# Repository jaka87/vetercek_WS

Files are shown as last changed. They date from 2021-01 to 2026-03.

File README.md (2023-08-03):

# Vetercek.com weather station
This project was created in order to provide cheap alternative to expensive autonomous weather stations. The goal is to create robust weather station that would require (almost) no maintenance. As mentioned in the title the data would be send to **vetercek.com** but with some modification other services could be included. Keep in mind that most attention is dedicated to measure wind since is used mostly by windsurfers, kiters and other wind enthusiast. In general we tried to keep the cost as low as possible on the other hand in some areas like for example anemometer we went with durable and well calibrated instead of cheap.

## Connecting options
+ [latest version with 7070 chip](vetercek_SIM7070) 
+ [old 7000 chip](vetercek_nb-iot-HW) 

## License
This project is released under
The GNU Lesser General Public License (LGPL-3.0)

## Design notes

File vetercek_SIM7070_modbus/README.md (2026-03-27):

# Vetercek.com weather station nb-iot
New PCB  
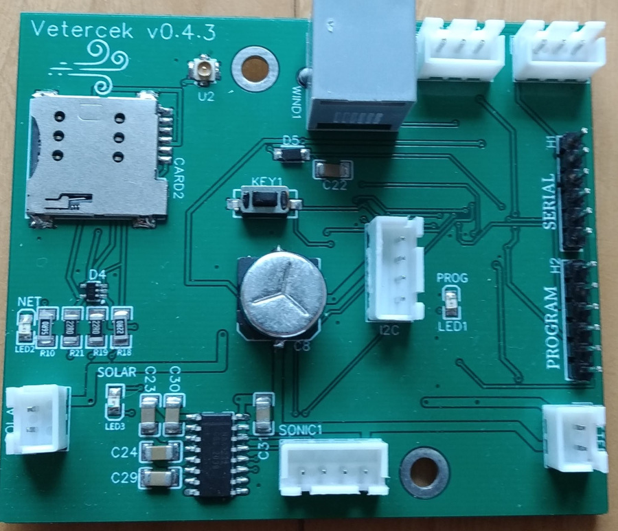
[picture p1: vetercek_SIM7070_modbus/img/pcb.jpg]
PCB
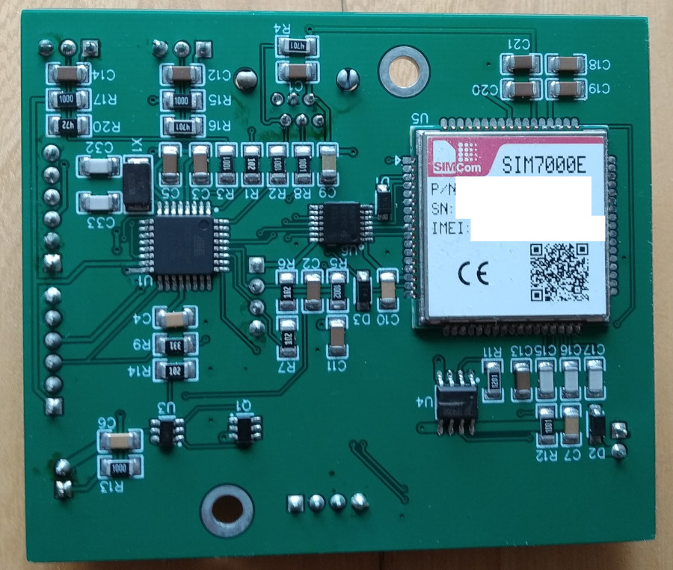
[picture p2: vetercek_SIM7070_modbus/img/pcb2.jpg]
PCB back
    

## Features of the WS
+ Send wind speed and gusts to the server
+ Send water and air temperature to the server
+ Send WS battery state to the server
+ Remote adjustment of the time between updates (depending on sever response)
+ Remote adjustment of wind wane offset (depending on sever response)
+ Wind speed and direction are measured for 2 second every 10 seconds (adjustable). It is a good compromise for accurate measurements and long battery life.
+ **New** switched from HTTP and MQTT to custom UDP protocol - for speed, reliability and better battery consumption 
+ **New** new GPRS modul that supports both nb-iot and also 2G (Thanks to [A1](https://www.a1.si/) and [Telekom Slovenije](https://www.telekom.si/) for providing me with nb-iot sim cards). With new module there is much faster data upload and lower battery consumption. Therefore I also enabled fast data upload that can be enabled when you need data upload every few secconds as opposed to few minutes.

## Required parts
+ ultrasonic anemometer RS232 
+ PCB with SIM7000E module 
+ SIM card 
+ 5 or 6V Solar Power Panel 
+ 3.6V li-ion batteries
+ Waterproof housing
+ GSM antena
+ DS18B20 temperature sensor
+ Cable gland for anemometer cable, solar and temperature sensor

## Optional parts
+ Rain gauge (whichever uses reed switch in tipping bucket)
+ BMP280 pressure sensor

## Payload
UDP payload using this station is 24 byte for upload and 9 bytes for server response  
**sample upload:**  
list=[11,11,11,11,11,11,11,1,   1,77, 12,2, 14,5, 1,20,3, 0,1,0, 77,18,40,0.88,12,34]  
+ first 8 bytes are id of the station
+ byte 9 and 10 are for wind wane -  (sample 177)
+ byte 11 and 12 are wind speed (sample 12.2 KT)
+ byte 13 and 14 are for gusts (sample 14.5 KT)
+ byte 15-17 are for air temperature (sample +20.3 C)
+ byte 18-20 are the same as above exept for water temperature (sample -1.0 C) or rain data
+ byte 21 is battery percentage (sample 77%)
+ byte 22 is signal 
+ byte 23 is count of measurements
+ byte 24 is reset reason  
+ byte 25 is solar current  
+ byte 26,27 is pressure measurement  

list=[40, 1,2,30, 23, 1, 5, 1, 0]  
**sample response:**
+ byte 1 is measure count - after how many measurements do the next data upload (sample 40)
+ byte 2-4 is for wind wane offset - (sample 230)
+ byte 5 is wind measurement timer (on client side this number is muultiplied by 10) - (sample 2300)
+ byte 6 controls tmp sensor - 0 off; 1 only air, 2 only watter; 3 both
+ byte 7 controsl cuttof wind  - when avg wind is under that value data is send 2x of setted interval
+ byte 8 - 0 no sleep between wind measurements, 1 - 8s delay
+ byte 9 - 1 resets the station, other numbers change settings of rain/water sensor, solar measurement, pressure measurement...

## Arduino pro mini
Arduino pro mini has different bootloader than Uno (older) that has watchdog bug that puts your arduino in endless loop. I solved this with uploading with programmer (skipping bootloader). If you wish to use bootloader I suggest Minicore. 

## Scheme
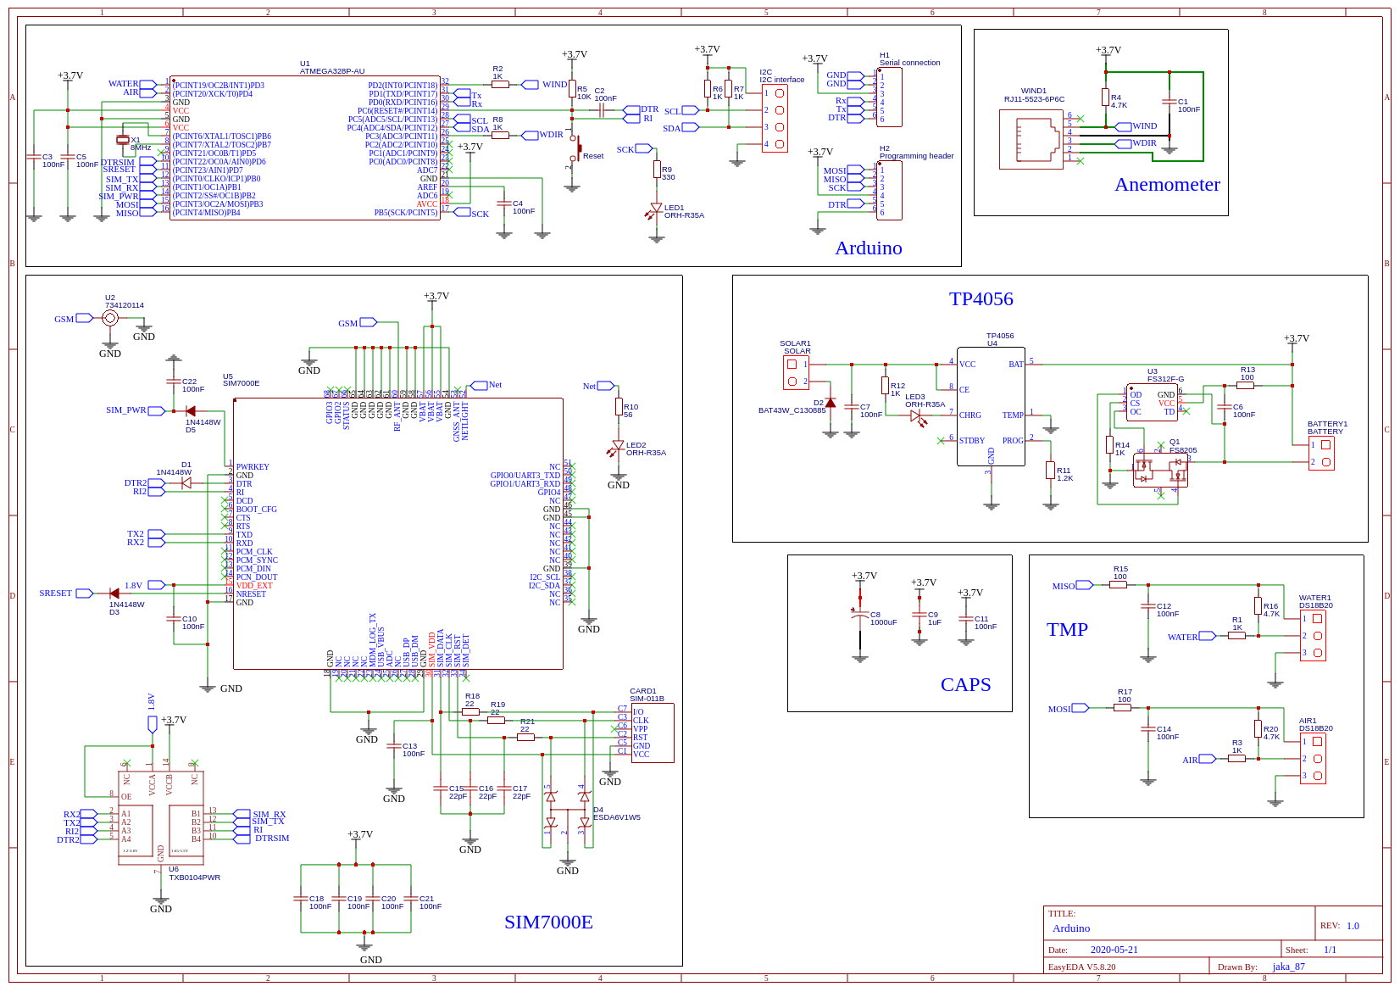
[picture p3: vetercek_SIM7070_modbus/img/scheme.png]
Scheme
  
Here is the [link](https://easyeda.com/jaka87/new-vetercek) to PCB design.  

## TO-DO
+ Currently there are no planned updates. WS seems stable and (almost) ready for production

## Libraries used in this project
All the libraries are uploaded in src folder. Most of them are stock libraries but i did quite some modification os SIM7000 library 

## Power consumption
In sleep 1-1.5mA  
Idle 4-5 mA (Davis anemometer) and 20-25mA (ultrasonic anemometer)   
Sending data 100-200mA  

## Thanks!
Thanks to all of you contributing to make this happen. Especially thanks to Tadej Tašner for drawing PCB and his advices regarding the hardware components. Also thanks to those people that took time and wrote libraries used in this project and therefore make the project easier to compile.

Contributing to this software is warmly welcomed. You can use it, change it, do what ever you want with it.

## License
This project is released under
The GNU Lesser General Public License (LGPL-3.0)

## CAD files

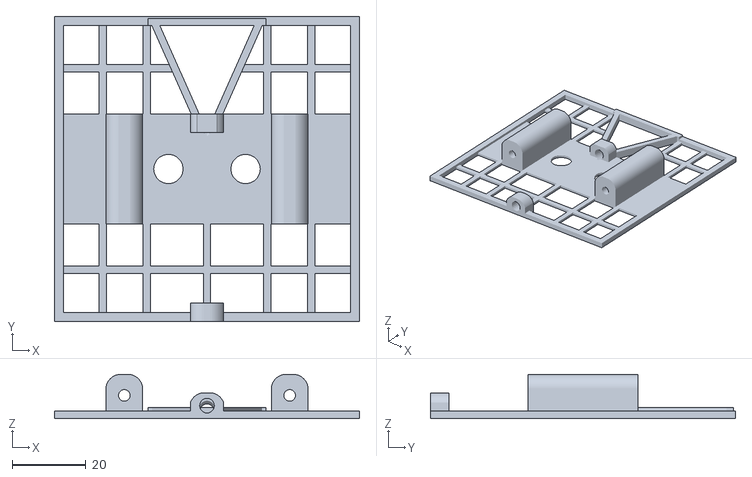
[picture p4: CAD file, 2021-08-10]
3D prints/solar/solar glued v2.stl
83.0 x 83.0 x 12.0

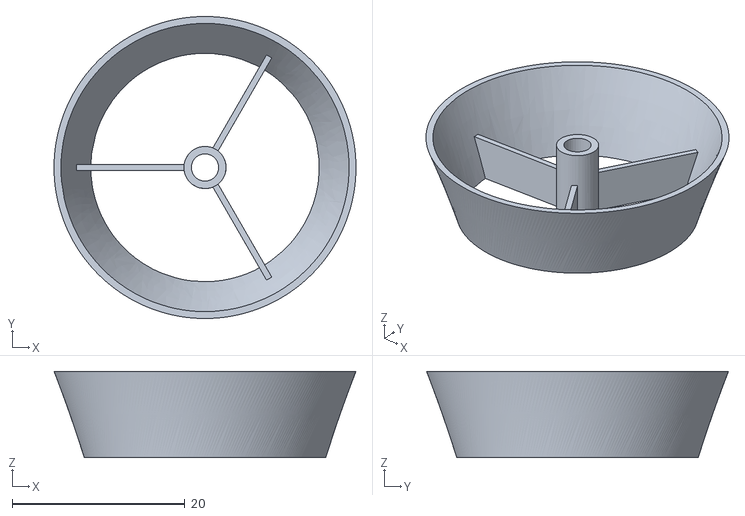
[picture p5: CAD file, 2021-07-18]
3D prints/tmp/35mm/tmp.stl
35.0 x 35.0 x 10.0

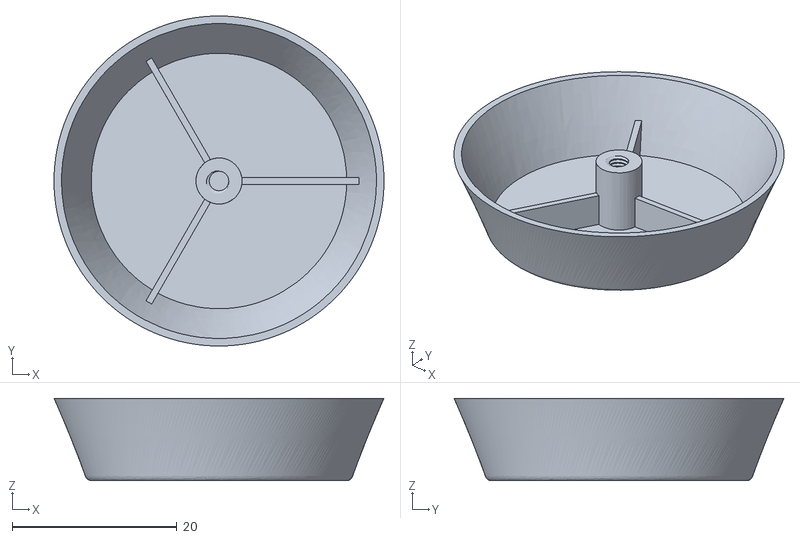
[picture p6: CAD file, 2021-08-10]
3D prints/tmp/40mm/tmp - top.stl
40.0 x 40.0 x 10.00

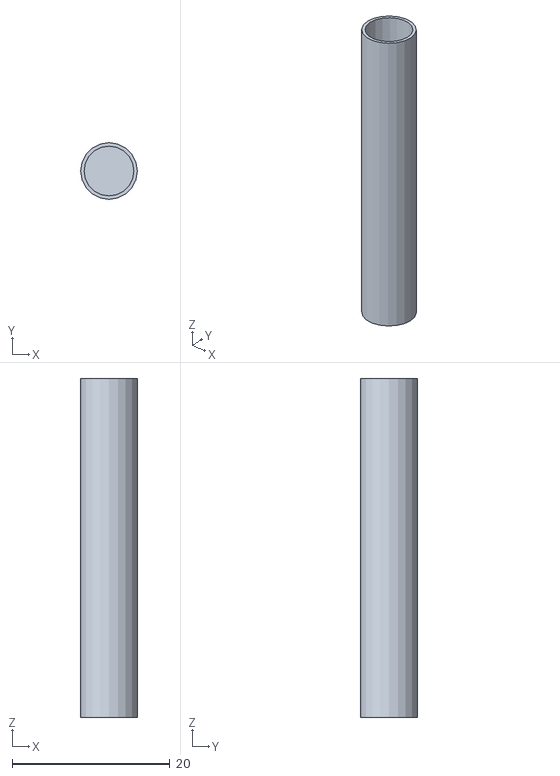
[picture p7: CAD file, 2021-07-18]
3D prints/tmp/tmp pipe.stl
7.20 x 7.20 x 43.0

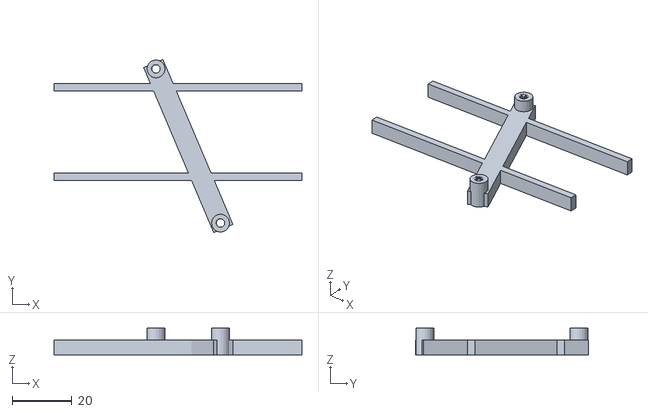
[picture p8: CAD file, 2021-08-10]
3D prints/WS box/PCB holder UZ.stl
83.0 x 58.0 x 9.00

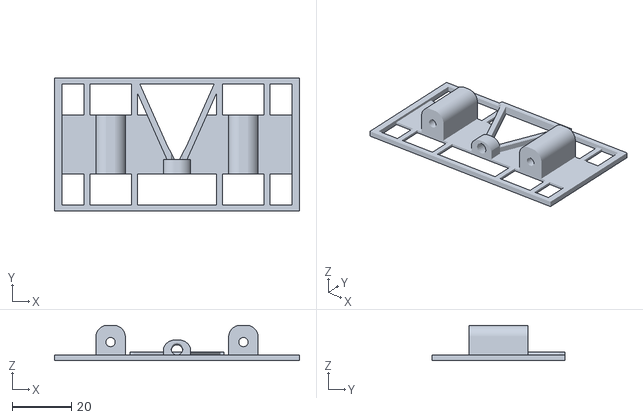
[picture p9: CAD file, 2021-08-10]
3D prints/solar/solar glued v2 small.stl
83.0 x 45.0 x 12.0

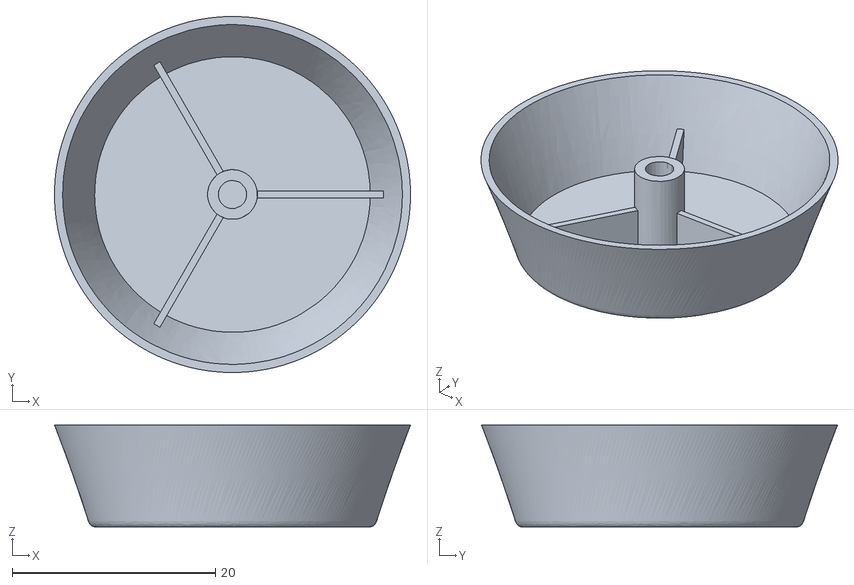
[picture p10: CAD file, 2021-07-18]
3D prints/tmp/35mm/tmp cover.stl
35.0 x 35.0 x 10.0

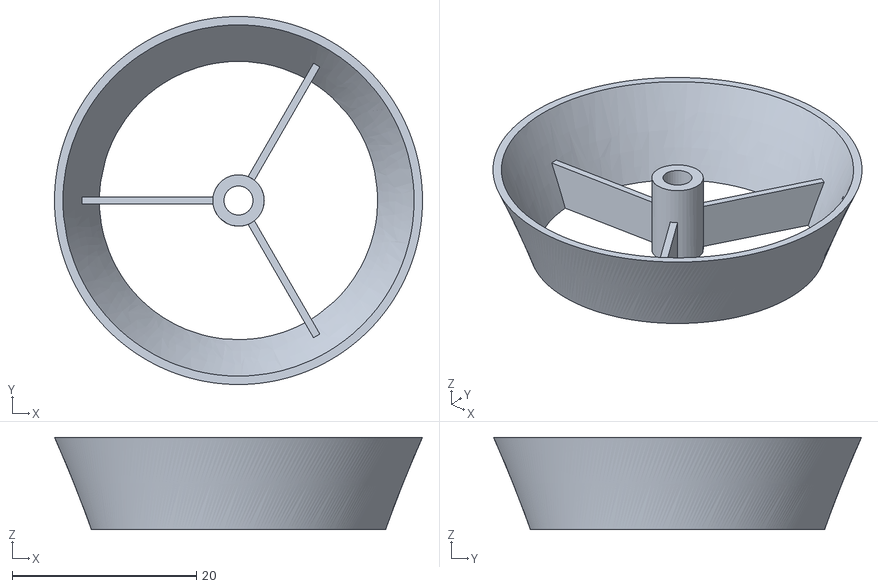
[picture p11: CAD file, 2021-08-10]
3D prints/tmp/40mm/tmp - midle.stl
40.0 x 40.0 x 10.0

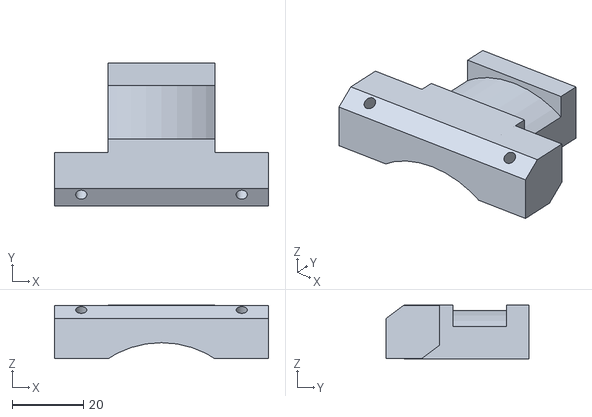
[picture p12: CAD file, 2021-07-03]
3D prints/solar/pole mount solar.stl
60.0 x 40.0 x 15.0

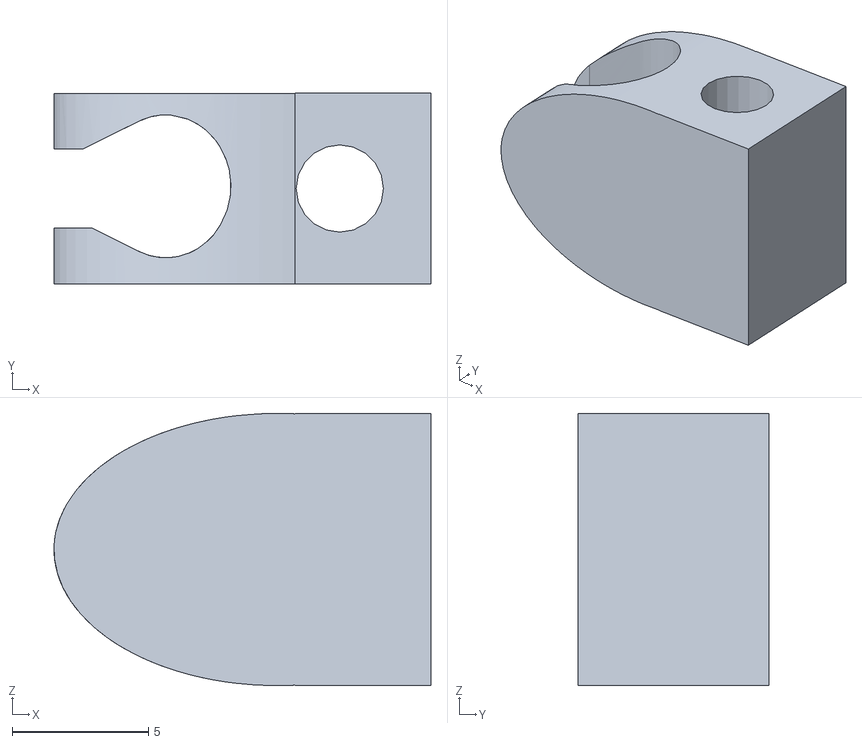
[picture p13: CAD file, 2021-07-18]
3D prints/tmp/35mm/cable clip2.stl
13.8 x 7.00 x 10.0

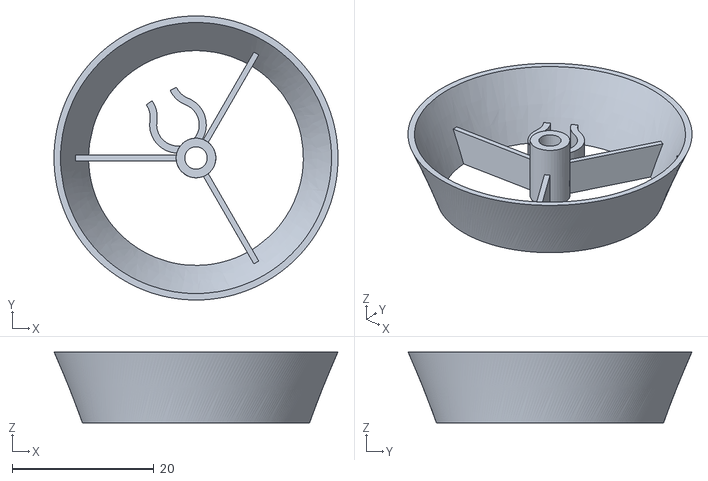
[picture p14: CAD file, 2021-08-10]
3D prints/tmp/40mm/tmp - bottom.stl
40.0 x 40.0 x 10.0

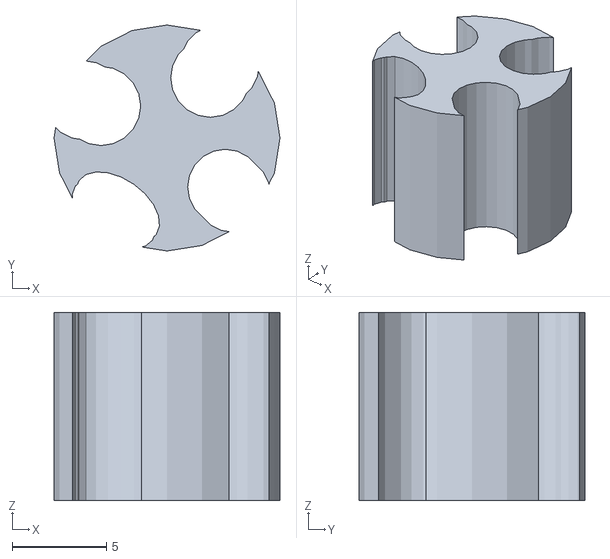
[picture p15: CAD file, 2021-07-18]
3D prints/WS box/PG gland insert 4.stl
12.0 x 12.0 x 10.0

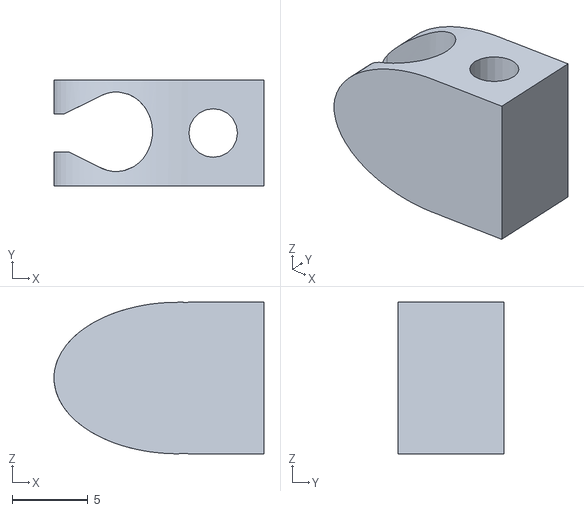
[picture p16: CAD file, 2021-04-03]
3D prints/tmp/35mm/cable clip.stl
13.9 x 7.00 x 10.0

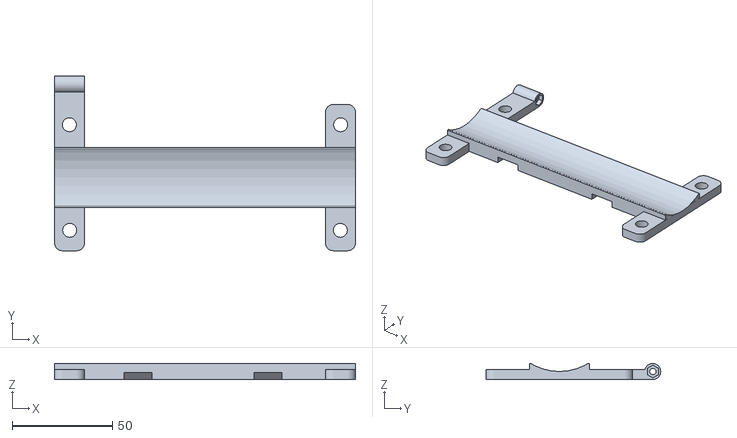
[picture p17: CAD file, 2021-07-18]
3D prints/WS box/box holder.stl
150.1 x 87.0 x 8.00

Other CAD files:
3D prints/WS box/PCB holder Davis.stl
3D prints/WS box/PG gland insert 3.stl
3D prints/solar/solar glued.stl

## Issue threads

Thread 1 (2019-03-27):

Doube data send in matter of few seconds

jaka87, 2019-03-27:
Once or twice a day data is send twice in matter of 30-60 seconds of one another, while second upload contains only one measurement. Im not sure exactly where the problem occurs or if its a problem with my code or SIM800 library.

The second upload contains only one measurement so wind speed and gust are identical. This should not have happen. I tried to add locking mechanism in loop function but that didn't solve the problem. Now I added second if condition in senddata() hoping it will solve it...

It could be caused by random arduino board reset. Im looking into it. Opinions welcomed.

jaka87, 2019-03-27:
It might very well be that arduino reset itself because of problem with serial print buffer. Some changes have been made to enable/disable debug mode. Few days of testing will show if error is fixed...

jaka87, 2019-04-01:
I tested with turned off serial print and increased posting frequency (to increased chances of error if issue still persist) and it appears the issue is still there

jaka87, 2019-04-02:
Some debugging has showed that error is caused by arduino board reset. Now the question is, if reset is because hardware malfunction or memory error. I will make an update in the evening with the function to display available memory on every post to see which one is it.

jaka87, 2019-04-03:
Latest commit seems to fix the issue. The problem was that somewhere down the line i removed the water sensor initial command by mistake. I also split water and temperature sensor reading to two different functions. Now battery is much more stable, error haven't shown up until now. Hope this is finally fixed.

jaka87, 2019-04-08:
After minor software update and checking the pins the error didn't appear in few days. Mark as solved. Fingers crossed.

Closed 2019-04-08.

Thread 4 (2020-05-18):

ultrasonic anemometer

jaka87, 2020-05-18:
The plan is to create cheap ultrasonic anemometer with good stability in all weather conditions and reasonable accuracy around 1 m/s or less.

Unfortunately my knowledge in this area is lacking but Im slowly learning and i hope that one day we will have working product. The principle is quite simple. Transmitter sends ultrasonic signal to receiver which measure time it took for this process. I first tried to use HC-SRO4 ultrasonic arduino module which is cheap an aveliable. I did some measurements and got accuracy of 1%. I thought this will be enough until i did some calculations. As it turns out i would need repeatability of less than  1 us but in reality my results were +- 5 us. Then I came up with neet idea to make 100 measurements, order it by time and use only 40-50 on that list to calculate average. That did improve results but not near enough for needed accuracy.

I found out that HC-SRO4 transmitter uses 40KHz and has amplitude of 25us and that this is just not enough to accurately measure time of flight - "tof". I search online and find couple of similar projects. I read them many times since its difficult topic for me. My knowledge did improve but im still not certain that i understand it well enough. The most important part of the design is analog component that amplifys signal  detect envelope and phase changes. Counting phase changes should give much more repeatable results.

Antiath, 2020-05-18:
I sure didn't expect to be notified out of nowhere about this subject.
So...about my part.
First of all, my version of this project is, as of today, still unfinished. I got together a prototype on perfboard that was kind of working. A lot of work and multiple revisions  had already been done. I decided to tanslate this prototype on a proper pcb but  those pcb didn't work and destroyed a bunch of pricey components. I got extremely frustrated and stopped working on it. I do plan on getting back to it (the device is actually just beside me right now) when motivation and time are available.

Now for what I can contribute on this, here are a few things I can mention:

1) My design is heavily inspired by Lukas's and carl's versions. It's a mix of both with my own tweaks.  But as the pcb files are clearly no good, there is no point in sharing my schematics. Sorry.

2) This is a crucial point : I use sully enclosed waterproof transceivers similar to these ( in shape only, not necessarly in performance):
https://im01.itaiwantrade.com/b6707fc1-c8f0-43e2-8f2c-90ac3ec62dbf/sensor_40CA-18S-2_thumb_630_447-480x480.jpg
I think this is important  because those things will go outside and they have to survive even in nasty conditions ( like heavy wind and heavy rain).
This way, I get signals that are way way lower in amplitude compared to the kind of open transceivers used HC-SRO4. It is still manageable but this means I need to crank up as much as possible the amplitude the signal I send . And also I need to put extra care on the amplifier on the receiving end.  Fortunatly for us, we deal with onely one frequency (40khz) so it is not impossible to extract from a noisy signal.

3) You are right, I did decide to use a Teensy 3.6 in the end. It can be programmed using the arduino environment (altough it needs special C code for the square signal generation, the kind of thing you won't find in arduino libraries or on the arduino forums) and it is blasing fast for a microcontroller ( and now the teensy 4 is even faster). That or Lukas's pic32 give plenty of margin to be able to do some math without slowing the whole system down. And, most importantly, they can actually output 40khz square signals without issues. The arduino can barely do it on it's own it just can't sample the received signals fast enough with its slow adc.

4) The phase detection part is hard. Very hard. For a lot of tricky reasons. The working prototype I have( the one on perf board) is using Lukas' method of detection. I fiirst detect the actual packet with the treshold method. Then I detect the zero crossings of each 40 khz oscillations and I use those to trigger the adc to do a sample of the received ( amplified) signal on the maximums and minimums of the packet ( so at least one sample at every 40 khz oscillation, on the high and low peaks). This gives me a very rough measure of the shape of the packet.  To mesure the phase, you have two options:

-you try and find the maximum  of the whole packet,  wich may not be the highest peak, it is probably somewhere in between two oscillations. So anywhere in a 25 µs span... Not very good... the peaks of those oscillation almost form a parabola so you can try to calculate the position of the maximum of this parabola with a bit of math ( method described in chapter 2.1 of this article: https://www.imeko.org/publications/wc-2006/PWC-2006-TC4-028u.pdf)  That would be nice if the packet wan't so spread out. Around the maximum, the peaks are so close to each other in amplitude that it becomes hard to and questionnable to do this calculation.  Add to this the fact that this is the real world. So you have noise messing with those amplitudes.

-you can try Lukas's way and do what is called a cross correlation of the packet with an packet measured at zero wind ( the values ar stored in memory) . This is a bit more math involved as you calculate an integral but in theory, it is more precise as you take the shape of the whole packect into account. I won't go into the details here, this is a bit too complicated for this kind of post.
 -----> In the end, both methods give pretty much the same results because there is just too much noise to tell them apart.  It is still usable with a LOT of average over as much packets as possible ( right now, my version i averaing over 2 or 3 seconds and I send a packet every 1.5 ms or so.). My prototype still has weird quirks and glitches that I didn't manage to resolve but it can measure  wind speed that make sense ( tested with a big fan blowing over the apparatus and calibrated with a cheap handheld anemometer)  and directions. To resolve a lot of issues, like you suggested, it may be important to use faster transceivers ( like 80 kHz or higher). They could give cleaner packets that are less spread out. It could allow easier measurement of the maximum. I know that commercial anemometers similar to what we are doing are using such ultrasonic cells. But this also means faster electronic, so more cost and more complexity. Also, they drive at something like 100 V peak to peak. I'm not going over 12V p-p.

5) Another issue is impedance matching. Right now , my version has no method of matching the impedance of the transceivers and I don't recall Lukas and Carl talking about that. Hardy Lau did mention it but he has access to the expensive tech ( that vector network analyzer)  needed to do that kind tweaking.  But in theory, this would allow to drive the tranceivers in a more suitable way so that the ultrasonic packets  ar sharper, cleaner with less spread.

Finally, as I already mentioned, Signal to noise ratio is an issue for me. But if people could assure me that open transceivers can be used outside without risking to destroy them as soon as it rains, I sure would like to use them.

SO... as you can see, there is a LOT to talk and think about.

As i understand, you want to simplify the device to use the HC-SRO4 as the driver and deal yourself with only the analog receiver part. If we forget about the open cells, it may be a good idea actually. Just verify that the driver is consistent ( meaning that it always need the same amount of time to send a packet when you trigger it with the arduino) . If not, it will be tricky.

Whatever you decide to do, I bid you good luck because this is not an easy project to make at low cost.

jaka87, 2020-05-18:
Hi @Antiath and thanks for detailed explanation. It will take me some time to fully understand because like i mentioned i dont have a lot of experience in this area. Also sorry for tagging you out of nowhere. I noticed you were frequent poster on Lukas's blog and i also found some website that mentioned you successfully did  your own project. After i was searching for a way to contact you with little luck. I did send you msg on twitter few days ago but didn't want to go further to try to track you on ever forum you posted. I am not a stalker (at least i like to think that way :) )

I understand this project is very chalenging but i would still like to give it a try. I agree that open sensors would not work in field Im just using them for trial. The low cost is not the main goal, but i would like to make it for 100$ or less. The Weatherflow anemometer (the one from the PCB above) cost me around 230$ together with the temperature sensor and wifi hub so i am asuming that it should be possible.  I was thinking of using https://si.farnell.com/multicomp/mcusd14a40s09rs/transceiver-40khz-14mm-metal/dp/2362679 i believe you use similar ones. I am also open to use transducers with higher Mhz.

At first i was thinking of trying to use the HC-SRO4 as transmitter (digital part) and i would use analog part from Lukas's design just to try things out. Later i probably wouldn't use arduino and i might even try to replicate Lukas design, or I might do that first. I dont know jet. Im changing my mind every few days :) One thing is for sure. I would very much like to make ultrasonic anemometer that could connect to my weather station. It was a big milestone for me and some friends that we even came that far and make a functional station. It took some time to squash most of the bugs (hopefully all) and stations are working well in the field for half of the year. Keeping it open source and not charging margin on parts make it also very cheap (4x) compare to commercial stations and people from windsurfing community are contacting me left and right if we can set some more stations. We use difficult locations and im not sure how long mechanical parts will last and that's why i was thinking of ultrasonic solution. Hopefully in few years we could use ultrasonic anemometer instead of mechanic one.

Since im tagging people out of nowhere its only appropriate that i add @soldernerd just in case you have to add something. If nothing else i just want to say thanks for your contribution. I visit your blog several times a day since you did most detailed contribution in this area. I bet you never had so much traffic on your site from Slovenia that you did in last 30 days  :)

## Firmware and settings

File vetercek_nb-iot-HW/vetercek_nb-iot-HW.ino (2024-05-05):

//bin/avrdude -C//etc/avrdude.conf -v -V -patmega328pb -cusbtiny -Uflash:w:/vetercek_nb-iot-HW.ino.hex:i lfuse:w:0xEF:m efuse:w:0xFF:m hfuse:w:DA:m lock:w:0xFF:m 
// 57600 max baud rate
// before uploading skech burn bootloader
// hardware serial buffer 128b 

//ultrasonic anemometer To active ASCI.
//>UartPro:2\r\n
//>SaveConfig\r\n


#include <avr/wdt.h> //watchdog
#include "src/LowPower/LowPower.h" //sleep library
#include <math.h> // wind speed calculations
#include "src/OneWire/OneWire.h" //tmp sensor
//#include "src/DS18B20/DS18B20.h"
#include "src/DS18B20/DallasTemperature.h"
#include "src/TimerOne/TimerOne.h"
#include "src/bmp/ErriezBMX280.h"
#include "src/Fona/Adafruit_FONA.h"
#include <avr/interrupt.h>
#include <EEPROM.h>
int resetReason = MCUSR;


//////////////////////////////////    EDIT THIS FOR CUSTOM SETTINGS
#define APN "iot.1nce.net"
int GSMnetwork1= 29340; // A1 SLOVENIA
int GSMnetwork2= 21910; // A1 HR
int GSMnetwork3= 21902; // tele2 2g HR
byte GSMstate=13; // default value for network preference - 13 for 2G, 38 for nb-iot and 2 for automatic
byte cutoffWind = 0; // if wind is below this value time interval is doubled - 2x
int vaneOffset=0; // vane offset for wind dirrection
int whenSend = 10; // interval after how many measurements data is send
const char* broker = "vetercek.com";
int sea_level_m=5; // enter elevation for your location for pressure calculation
/////////////////////////////////    OPTIONS TO TURN ON AN OFF
//#define DEBUG // comment out if you want to turn off debugging
#define UZ_Anemometer // if ultrasonic anemometer - PCB minimum PCB v.0.5
#define HUMIDITY 31 // 31 or 41 or comment out if you want to turn off humidity sensor
//#define BMP // comment out if you want to turn off pressure sensor and save space
//#define TMPDS18B20 // comment out if you want to turn off humidity sensor
//#define TMP_POWER_ONOFF // comment out if you want power to be on all the time
//#define SIM_NEW_LIBRARY
///////////////////////////////////////////////////////////////////////////////////

#ifdef SIM_NEW_LIBRARY 
  #include "src/SIM/BotleticsSIM7000.h"
#else
  #include "src/Fona/Adafruit_FONA.h"
#endif

#define ONE_WIRE_BUS_1 4 //air
#define ONE_WIRE_BUS_2 3 // water
#define windSensorPin 2 // The pin location of the anemometer sensor
#define USRX 11
#define USTX 12
#define PWRAIR 8
#define PWRWATER 9  
#define windVanePin PIN_A3       // The pin the wind vane sensor is connected to
#define DTR 6
#define PWRKEY 10
#define ENABLE_UART_START_FRAME_INTERRUPT UCSR1D = (1 << RXSIE) | (1 << SFDE)
#define DISABLE_UART_START_FRAME_INTERRUPT UCSR1D = (0 << RXSIE) | (0 << SFDE)

byte data[] = { 11,11,11,11,11,11,11,1, 0,0, 0,0, 0,0, 0,0,0, 0,0,0, 0,0,0,0,0, 0,0,0 }; // data


#ifdef TMPDS18B20
  #include "src/OneWire/OneWire.h" //tmp sensor
  #include "src/DS18B20/DallasTemperature.h"
  OneWire oneWire_in(ONE_WIRE_BUS_1);   //tmp
  DallasTemperature sensor_air(&oneWire_in);
  OneWire oneWire_out(ONE_WIRE_BUS_2);
  DallasTemperature sensor_water(&oneWire_out);
#endif

//////////////////////////////////    EEPROM DATA
// 1-8 IMEI
// 9   2G/nb-iot
// 10  water temperature or rain
// 11  solar on/off - since 0.4.4
// 12  ultraasonic on/off
// 13  pressure on/off
// 15 additional debug data
      //1 ultrasonic not connected
      //2 timer 200s
      //3 manual reset
      //4 ultrasonic check fail

//////////////////////////////////    RESET REASON
// 81 - UZ 10 errors in loop function
// 82 - unable to send data in 200s
// 83 - manual remote reset 
// 84 - X sonic errors in UZ function
// 85 - UDPclose
// 86 - gsm NC
// 88 - other
// 89 - no GSM serial connection


HardwareSerial *fonaSS = &Serial;
#ifdef UZ_Anemometer
   #define ultrasonic Serial1
#endif
#ifdef DEBUG
  #include <NeoSWSerial.h>
  NeoSWSerial DEBUGSERIAL( 5, 7 ); 
#endif



#ifdef SIM_NEW_LIBRARY 
  Botletics_modem_LTE fona = Botletics_modem_LTE();
#else
  Adafruit_FONA_LTE fona = Adafruit_FONA_LTE();
#endif

#ifdef BMP
  #include "LPS35HW.h"
  const uint8_t address = 0x5D; 
  LPS35HW lps(address);
#endif

#ifdef HUMIDITY
  #include "Wire.h"
  #if HUMIDITY == 31
    #include "src/HUM/SHT31.h"
    #define SHT_ADDRESS   0x44
    SHT31 sht;    
  #else
    #include "src/HUM/SHT4x.h"
    SHT4x sht;
  #endif
#endif

//////////////////////////////////    RATHER DON'T CHANGE
unsigned int pwrAir = PWRAIR; // power for air sensor
unsigned int pwrWater = PWRWATER; // power for water sensor
int windDelay = 2300; // time for each anemometer measurement in miliseconds
byte onOffTmp = 1;   //on/off temperature measure
volatile unsigned long timergprs = 0; // timer to check if GPRS is taking to long to complete
volatile unsigned long rotations; // cup rotation counter used in interrupt routine
volatile unsigned long contactBounceTime; // Timer to avoid contact bounce in interrupt routine
volatile unsigned long lastPulseMillis; // last anemometer measured time
volatile unsigned long firstPulseMillis; // fisrt anemometer measured time
volatile unsigned long currentMillis;
volatile unsigned long currentMillis2;
volatile unsigned long contactBounceTime2; // Timer to avoid contact bounce in rain interrupt routine
volatile unsigned long updateBattery = 0;

int rainCount=-1; // count rain bucket tilts
byte SolarCurrent; // calculate solar cell current 
byte firstWindPulse; // ignore 1st anemometer rotation since it didn't make full circle
int windSpeed; // speed
long windAvr = 0; //sum of all wind speed between update
int windGust[3] = { 0, 0, 0 }; // top three gusts
int windGustAvg = 0; //wind gust average
int measureCount = 0; // count each mesurement
float water=99.0; // water Temperature
float temp=99.0; //Stores Temperature value
int vaneValue;       // raw analog value from wind vane
int direction;       // translated 0 - 360 direction
int calDirection;    // converted value with offset applied
int windDir;  //calculated wind direction
float windAvgX; //x and y wind dirrection component
float windAvgY;
int wind_speed;  //calculated wind speed
int wind_gust;   //calculated wind gusts
int battLevel = 0; // Battery level (percentage)
uint16_t battVoltage = 0; // Battery voltage
unsigned int sig = 0;
int idd[15];
byte sleepBetween=2;
int PDPcount=0; // first reset after 100s
byte failedSend=0; // if send fail
byte sonicError=0;
byte sonicError2=0;
byte UltrasonicAnemo=0;
byte enableSolar=0;
byte enableRain=0;
byte enableBmp=0;
int pressure=0;
byte changeSleep=0;
byte batteryState=0; // 0 normal; 1 low battery; 2 very low battery
byte stopSleepChange=0; //on
volatile byte countWake = 0;
byte enableHum=0;
byte humidity=0;


void setup() {
  MCUSR = 0; // clear reset flags
  wdt_disable();
  
  Timer1.initialize(1000000UL);         // initialize timer1, and set a 1 second period
  Timer1.attachInterrupt(CheckTimerGPRS);  // attaches checkTimer() as a timer overflow interrupt

  pinMode(PWRKEY, OUTPUT);
  digitalWrite(PWRKEY, LOW);
  pinMode(13, OUTPUT);     // this part is used when you bypass bootloader to signal when board is starting...
  digitalWrite(13, HIGH);   // turn the LED on
  delay(500);              // wait
  digitalWrite(13, LOW);    // turn the LED
  delay(50);
  pinMode(pwrAir, OUTPUT);      // sets the digital pin as output
  pinMode(pwrWater, OUTPUT);      // sets the digital pin as output
  digitalWrite(pwrAir, HIGH);   // turn on power
  digitalWrite(pwrWater, HIGH);   // turn on power  
  pinMode(DTR, OUTPUT);
  digitalWrite(DTR, LOW); 
  pinMode(PIN_A2, OUTPUT);
  digitalWrite(PIN_A2, HIGH);   
  
  #ifdef UZ_Anemometer
    ENABLE_UART_START_FRAME_INTERRUPT;
  #endif


  
#ifdef DEBUG
  DEBUGSERIAL.begin(9600);
  delay(20);
  DEBUGSERIAL.println(F("S"));
  DEBUGSERIAL.println(resetReason);
  //Serial1.begin(9600); //for sim7000 debug
#endif



#ifdef TMPDS18B20
  sensor_air.begin();
#endif

if (EEPROM.read(11)==255 or EEPROM.read(11)==1) {  enableSolar=1; }   
  if (EEPROM.read(10)==0) { attachInterrupt(digitalPinToInterrupt(3), rain_count, FALLING); enableRain=1;} // rain counts
  #ifdef TMPDS18B20
    else { sensor_water.begin(); } // water temperature
  #endif  
  if (EEPROM.read(9)==13) { GSMstate=13; }
  else if (EEPROM.read(9)==2) { GSMstate=2; }
  else if (EEPROM.read(9)==38) {GSMstate=38; } //#define NBIOT
  else if (EEPROM.read(9)==51) {GSMstate=51; } //#define NBIOT
  if (EEPROM.read(14)==10) { stopSleepChange=3; } // UZ sleep on/off

#ifdef BMP
  if ((EEPROM.read(13)==255 or EEPROM.read(13)==1) and lps.begin()) {  
      enableBmp=1; 
      lps.setLowPower(true);
      lps.setOutputRate(LPS35HW::OutputRate_OneShot);   
      }
#endif   

#ifdef HUMIDITY
  #if HUMIDITY == 31
    Wire.begin();
    sht.begin(SHT_ADDRESS);
    Wire.setClock(100000);
    uint16_t stat = sht.readStatus();
  
      if ( sht.isConnected() ){
        enableHum=1;
      }
  #else
    Wire.begin();
    sht.setChipType(SHT4X_CHIPTYPE_A);
    sht.setMode(SHT4X_CMD_MEAS_HI_PREC);
  if (sht.checkSerial() == SHT4X_STATUS_OK) {
    enableHum=1;
  }
  #endif 
#endif

delay(4000);  
digitalWrite(PWRKEY, HIGH);
moduleSetup(); // Establishes first-time serial comm and prints IMEI 
bool checkAT = fona.checkAT();
if (fona.checkAT()) { checkIMEI(); }
connectGPRS(); 


  if (resetReason==8 ) { //////////////////// reset reason detailed        
    if (EEPROM.read(15)>0 ) {
      if (EEPROM.read(15)==1 ) { 
        resetReason=81; 
      }
      else if (EEPROM.read(15)==2 ) { 
        resetReason=82; 
      }  
      else if (EEPROM.read(15)==3 ) { 
        resetReason=83; 
      }  
      else if (EEPROM.read(15)==4 ) { 
        resetReason=84; 
      }      
      else if (EEPROM.read(15)==5 ) { 
        resetReason=85; 
      }  
    else if (EEPROM.read(15)==6 ) { 
      resetReason=86; 
    } 
    else if (EEPROM.read(15)==7 ) { 
      resetReason=87; 
    } 
    else if (EEPROM.read(15)==9 ) { 
      resetReason=89; 
    } 
      else { 
        resetReason=88; 
      }   
    EEPROM.write(15, 0); 
    } 
  } 


 

  beforeSend();

#ifdef UZ_Anemometer
  unsigned long startedWaiting = millis();
  UZ_wake(startedWaiting);
  if (millis() - startedWaiting <= (45000) ) {
    UltrasonicAnemo=1;
    windDelay=1000;
    ultrasonicFlush();
   #ifdef DEBUG
    DEBUGSERIAL.println(F("UZ"));
    delay(50);
  #endif  
  }
  else {
  #ifdef DEBUG
    DEBUGSERIAL.println(F("UZ fail"));
    delay(50);
  #endif  
    reset(7); // reset board if UZ not aveliable
  } 
  LowPower.powerExtStandby(SLEEP_8S, ADC_OFF, BOD_OFF,TIMER2_ON);  // sleep  
#endif 
}

void loop() {
     
#ifdef UZ_Anemometer
  DISABLE_UART_START_FRAME_INTERRUPT;    
  unsigned long startedWaiting = millis();

  while(ultrasonic.available() < 2 and millis() - startedWaiting <= 50) {  delay(10); }
  if (ultrasonic.available() < 2 ) { // sleep while receiving data and anemometer sleep time 3s or more
        LowPower.idle(SLEEP_2S, ADC_OFF, TIMER4_OFF,TIMER3_OFF,TIMER2_ON, TIMER1_OFF, TIMER0_OFF,SPI1_OFF,SPI0_OFF,USART1_ON, USART0_OFF, TWI1_OFF,TWI0_OFF,PTC_OFF);
  }
  else { // sleep while receiving data and anemometer sleep time 2s or less 
        LowPower.idle(SLEEP_120MS, ADC_OFF, TIMER4_OFF,TIMER3_OFF,TIMER2_ON, TIMER1_OFF, TIMER0_OFF,SPI1_OFF,SPI0_OFF,USART1_ON, USART0_OFF, TWI1_OFF,TWI0_OFF,PTC_OFF);
  }

    while (ultrasonic.read() != ',' and millis() - startedWaiting <= 7000) {  } 
    delay(90);
  
  if (ultrasonic.available()>61){  
    UltrasonicAnemometer();
    } 
  else {  
  ultrasonicFlush();
  } 
                    
#else 
    Anemometer();                           // anemometer
    GetWindDirection();

  if ( sleepBetween == 1)  { // to sleep or not to sleep between wind measurement
    LowPower.powerDown(SLEEP_1S, ADC_OFF, BOD_OFF);  // sleep
  }
  else if ( sleepBetween == 2)  { // to sleep or not to sleep between wind measurement
    LowPower.powerDown(SLEEP_2S, ADC_OFF, BOD_OFF);  // sleep
  }
  else if ( sleepBetween > 2 and sleepBetween < 7)  { // to sleep or not to sleep between wind measurement
    LowPower.powerDown(SLEEP_4S, ADC_OFF, BOD_OFF);  // sleep
  }
  else if ( sleepBetween >= 7 )  { // to sleep or not to sleep between wind measurement
    LowPower.powerDown(SLEEP_8S, ADC_OFF, BOD_OFF);  // sleep
  }
   
#endif  


  #ifdef DEBUG                                 // debug data
    DEBUGSERIAL.print(F(" d:"));
    DEBUGSERIAL.print(calDirection);
    DEBUGSERIAL.print(F(" s:"));
    DEBUGSERIAL.print(windSpeed);
    DEBUGSERIAL.print(F(" c:"));
    DEBUGSERIAL.print(measureCount);
    DEBUGSERIAL.print(F(" s:"));
    DEBUGSERIAL.println(sonicError);
  #endif

  GetAvgWInd();                                 // avg wind


  digitalWrite(13, HIGH);   // turn the LED on
  delay(50);                       // wait
  digitalWrite(13, LOW);    // turn the LED
 
// check if is time to send data online  
if ( measureCount >= ((whenSend*2)+40))   {  reset(6);  } // reset if more than 40 tries
if ( ((resetReason==2 or resetReason==5) and measureCount > 2)  // if reset buttion is pressed and 3 measurements are made
  or (wind_speed >= (cutoffWind*10) and measureCount >= whenSend ) // if wind avg exeeds cut off value and enough measurements are  made
  or (measureCount >= (whenSend*2))
  or (measureCount>500 ) // if more than 500 measurements
  )
  
  {  
    beforeSend();
  }
  
  else if ( UltrasonicAnemo==0 ){ // restart timer
    noInterrupts();
    timergprs = 0;                                
    interrupts();
  }

#ifdef UZ_Anemometer
  else if ( UltrasonicAnemo==1 ){ // go to sleep
      #ifdef DEBUG
      DEBUGSERIAL.print(F("wc "));
      DEBUGSERIAL.println(countWake);
    #endif   
    ENABLE_UART_START_FRAME_INTERRUPT;
    countWake=0;
    LowPower.powerExtStandby(SLEEP_8S, ADC_OFF, BOD_OFF,TIMER2_ON);  // sleep  
    }    

#endif 
}


void beforeSend() { 
      /////////////////////////// send data to server ///////////////////////////////////////////////  
//      #ifdef UZ_Anemometer
//        ultrasonic.end();
//      #endif
      GetTmpNow();
      digitalWrite(DTR, LOW);  //wake up  
      delay(10);
      bool checkAT = fona.checkAT();
        if (fona.checkAT()) { SendData(0); }
        else {moduleSetup(); SendData(0); }
      digitalWrite(DTR, HIGH);  //sleep  
      delay(50);

      #ifdef UZ_Anemometer
//        unsigned long startedWaiting = millis();
//        UZ_wake(startedWaiting);
        if (UltrasonicAnemo==1){
            if ( changeSleep== 1 and stopSleepChange<3) { //change of sleep time
          ultrasonicFlush();   
          UZsleep(sleepBetween);
            }
        }
      ultrasonicFlush();  
      ENABLE_UART_START_FRAME_INTERRUPT;
      LowPower.powerExtStandby(SLEEP_8S, ADC_OFF, BOD_OFF,TIMER2_ON);  // sleep  
      #endif    
}


void CheckTimerGPRS() { // if unable to send data in 200s
  timergprs++;
    
  if (timergprs > 200 ) {
    #ifdef DEBUG
      DEBUGSERIAL.println(F("hardR"));
    #endif    
    timergprs = 0;
    reset(2);
  }
}

void reset(byte rr) {
    if (rr > 0 ) {
      EEPROM.write(15, rr);
    }
  delay(20);
  #ifdef DEBUG
    DEBUGSERIAL.print(F("err_r: "));
    DEBUGSERIAL.println(rr);
  #endif  
  digitalWrite(PWRKEY, LOW);
  delay(4000);  
  wdt_enable(WDTO_60MS);
  delay(100);
}



void simReset() {
  digitalWrite(PIN_A2, LOW);     
  delay(300);   
  digitalWrite(PIN_A2, HIGH);  
}


#ifdef UZ_Anemometer
void UZ_wake(unsigned long startedWaiting) {
  while (!ultrasonic.available() && millis() - startedWaiting <= 45000) {  // if US not aveliable start it
    ultrasonic.begin(9600);
    delay(800);
    }      
}
#endif  



ISR(USART1_START_vect){
countWake++;
}

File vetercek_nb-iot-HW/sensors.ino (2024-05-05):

#ifdef UZ_Anemometer
void UltrasonicAnemometer() { //measure wind speed
    char buffer[70];
    char hexbuffer[5];
    char hexbuffer2[5]; // new anemometer with aditional 0 in string
    int sum;
    int sum2; // new anemometer with aditional 0 in string
    unsigned long startedWaiting = millis();
             

      int size = ultrasonic.readBytesUntil('\r\n', buffer, 70);
      buffer[size]='\0'; 

      delay(20); // important in case of error

       #ifdef DEBUG 
       delay(20);
        DEBUGSERIAL.print(size); 
        DEBUGSERIAL.print(F(" buff ")); 
        DEBUGSERIAL.println(buffer); 
       delay(20);
       #endif 
          
      char *dir = strtok(buffer, ",/");
      char *wind = strtok(NULL, ",/");
      char* check = strtok(NULL, ",/");

//       #ifdef DEBUG 
//       delay(20);
//        DEBUGSERIAL.println(dir); 
//        DEBUGSERIAL.println(wind); 
//        DEBUGSERIAL.println(check); 
//       delay(70);
//       #endif 

      if( check!=NULL and wind!=NULL and dir!=NULL)  {    
        sum+=countBytes(dir);
        sum+=countBytes(wind);
        sum+=2605;
        sum2=sum+48;
        sum=-(sum % 256);   
        sum2=-(sum2 % 256);   
        sprintf(hexbuffer,"%02X", sum);
        sprintf(hexbuffer2,"%02X", sum2); // new anemometer with aditional 0 in string
    
        if( (check[0] ==hexbuffer[2] and check[1] ==hexbuffer[3]) or (check[0] ==hexbuffer2[2] and check[1] ==hexbuffer2[3]) )  {  
              calDirection = atoi(dir) + vaneOffset;
              CalculateWindDirection();  // calculate wind direction from data
              windSpeed=atof(wind)*19.4384449;
              CalculateWindGust(windSpeed);
              CalculateWind();
              timergprs = 0;                                            
        }
        else { 
            UZerror(3); 
          }        
      }
      else { 
        UZerror(2); 
        }      

ultrasonicFlush();
}

int countBytes( const char * data )
{
  int total = 0;
  const char * p = data;
  while ( *p != '\0' )
  {
    total += *p++;
  }
  return total;
}

void UZerror(byte where) { //ultrasonic error
      ultrasonicFlush();
  sonicError++;
  #ifdef DEBUG
      DEBUGSERIAL.print(F("err UZ "));
      DEBUGSERIAL.println(where);
  #endif
if ( sonicError >=7)  { reset(4);  }   // if more than x US errors 
if ( sonicError2 >=7)  { reset(7);  }   // if more than x US errors 
}

void UZsleep(byte sleepT) { //ultrasonic anemometer sleep mode
  char buffer[35];
  char buffer2[80];
  byte slponoff=1;
  
  if (sleepT==0){slponoff=0;}
  //sprintf(buffer, ">PwrIdleCfg:%d,%d\r\n", slponoff,sleepT);  
  sprintf(buffer, ">PwrIdleCfg:%d,%d\r\n>SaveConfig\r\n", slponoff,sleepT);  



while (ultrasonic.available() <2) {  delay(10); } 
  unsigned long startedWaiting = millis();   
  #ifdef DEBUG
      DEBUGSERIAL.println(F("UZzzz"));
      delay(20);
  #endif

  byte trow_away;
  trow_away=(ultrasonic.read());
  int size = ultrasonic.readBytesUntil('\n', buffer2, 70);
  buffer[size]='\0'; 

  while (strstr (buffer2,"IdleSec") == NULL && millis() - startedWaiting <= 20000) {
    trow_away=(ultrasonic.read());
    size = ultrasonic.readBytesUntil('\n', buffer2, 70); 
    buffer2[size]='\0';   
    ultrasonic.write(buffer);  
    delay(100);
    }

    if(millis() - startedWaiting < 19900){ ultrasonic.write(">SaveConfig\r\n"); }
    if(millis() - startedWaiting < 19900){ 
      sleepBetween=sleepT;
      changeSleep=0;
      stopSleepChange=0;
     #ifdef DEBUG 
      DEBUGSERIAL.print(F("sleepcok ")); 
      DEBUGSERIAL.println(sleepT); 
      delay(10);
     #endif 
      }
    else { 
     stopSleepChange++;
     #ifdef DEBUG 
      DEBUGSERIAL.println(F("err sleepc")); 
     #endif       
      }
//  ultrasonicFlush();
//    while (ultrasonic.available() <2) {  
//      delay(5);
//      }  
//  ultrasonic.write(buffer);   
//  ultrasonic.write(">SaveConfig\r\n");
//
//  unsigned long startedWaiting = millis(); 
//  while (strstr (buffer2,"IdleSec") == NULL and millis() - startedWaiting > 10000) {
//    int size = ultrasonic.readBytesUntil('\n', buffer2, 80);
//    delay(50);
//  }
//
//    if(millis() - startedWaiting < 10000){ 
//      sleepBetween=sleepT;
//      changeSleep=0;
//      stopSleepChange=0;
//      ultrasonicFlush();
//     #ifdef DEBUG 
//      DEBUGSERIAL.print(F("sleepcok ")); 
//      DEBUGSERIAL.println(sleepT); 
//      delay(10);
//     #endif 
//      }
//    else { 
//     stopSleepChange++;
//     #ifdef DEBUG 
//      DEBUGSERIAL.println(F("err sleepc")); 
//     #endif       
//      } 
}
#endif 

#ifndef UZ_Anemometer
  void Anemometer() { //measure wind speed
    float actualWindDelay; //time between first and last measured anemometer rotation
    firstWindPulse = 1; // dont count first rotation
    contactBounceTime = millis();
    rotations = 0; // Set rotations count to 0 ready for calculations
    EIFR = (1 << INTF0); // clear interrupt flag
    attachInterrupt(digitalPinToInterrupt(windSensorPin), ISRrotation, FALLING); //setup interrupt on anemometer input pin, interrupt will occur whenever falling edge is detected
    delay (windDelay); // Wait x second to average
    detachInterrupt(digitalPinToInterrupt(windSensorPin));
  
  if (rotations == 0)  {
    windSpeed = 0;
  }
  else  {
    actualWindDelay = (lastPulseMillis - firstPulseMillis);
    windSpeed = rotations * (2250 / actualWindDelay) * 0.868976242 * 10 ; // convert to mp/h using the formula V=P(2.25/Time);
    // 2250 instead of 2.25 because formula is in seconds not millis   & * 0.868976242 to convert in knots   & *10 so we can calculate decimals later
  }

  if (windSpeed < 600) { // delete data larger than 60KT
      CalculateWind();
      CalculateWindGust(windSpeed);
  }

}
#endif

void CalculateWind() {  
    ++measureCount; // add +1 to counter
    windAvr += windSpeed; // add to sum of average wind values
}


void CalculateWindGust( int w ) {
      if (w >= windGust[2]) { // check if > than old gust3 of wind
        windGust[0] = windGust[1];
        windGust[1] = windGust[2];
        windGust[2] = w;
      }
    
      else if (w >= windGust[1]) { // check if > than old gust2 of wind
        windGust[0] = windGust[1];
        windGust[1] = w;
      }
    
      else if (w > windGust[0]) { // check if > than old gust1 of wind
        windGust[0] = w;
      }
      windGustAvg = (windGust[0] + windGust[1] + windGust[2]) / 3;
}

void GetAvgWInd() {
  wind_speed = windAvr / measureCount; // calculate average wind
}
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

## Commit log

2019-05-19 wifi added temperature sensor
2019-05-20 added PCB image
2019-05-23 wireless start commented out fix
2019-06-08 Removed tmp sensor adresses, rather let it auto select (apply to ether air or watter remotely). Also addes some options for easyer remote manipulation
2019-06-09 added option to detect number of tmp sensors and act accordingly
2019-06-16 dettach interrupt to enable sleep mode even when anemometer is rotating
2019-06-17 small change in tmp sensor
2019-06-18 split water and air temperature in two separate functions, to better handle disconnects
2019-07-26 additional resistor
2019-08-03 changes for new PCB, tmps sensors on separate ports, code changes for larger tmp sensor cable lenght
2019-08-03 fix battery 100%
2019-08-13 new pcb design
2019-08-19 fix if there is only one tmp sensor
2019-08-25 added function to check signal quality, no data on tmp sensors if not pluged, other changes to reflect updated library for sending data
2019-08-25 delay for tmp sensors
2019-08-26 if tmp sensor disconnects
2019-08-30 added led blink when station resets (when bootloader is bypased "nothing" happens when reset is pressed)
2019-08-31 turn on/off tmp sensor
2019-09-25 GPS location function removed since it causes arduino reset from time to time, signal quality function also removed since signal don't vary that much
2019-10-12 code and readme changes for pcb v.0.3 - remotely turn on/off tmp sensors, extra resistors to prevent short circuit on tmp sensors
2019-11-25 fix wind calculation because now time is in millis
2019-11-25 bracket missing in calculation
2020-02-21 updates for new PCB
2020-04-06 signal and battery voltage
2020-04-12 button reset
2020-11-02 Update vetercek_2G.ino
    added timer to check if the code is stuck and do a wd reset in that case
    fixed reset bug that sometimes happened when putting GSM module to sleep
2020-11-22 timer 10s
2021-01-09 dont send battery measurement every time
2021-01-11 tmp sensors on/off
2021-01-13 EEPROM fix for reset
    [network.ino]
2021-04-03 3d models updated
    [PCB holder.stl, PG gland insert.stl, box holder.stl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]
2021-06-04 ultrasonic adn serial fix
    [network.ino, sensors.ino]
2021-07-03 3d prints
    [PCB holder.stl, box holder.stl, holders.stl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]
2021-07-18 3d models and PCB images
    [PCB holder.stl, PG gland insert 3.stl, PG gland insert 4.stl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]
2021-08-27 pressure sensor, some additional interchangable online setings
2021-08-31 fix whensend value +150 bug, added pressure option
    [network.ino, sensors.ino]
2021-09-11 ultrasonic sleep
2021-12-31 0.5 board update
2022-01-04 longer sleep if low battery
2022-01-12 UZ sleep, current mesurement
2022-01-29 UZ + sleep fix
    [network.ino, sensors.ino]
2022-02-12 if sleep > low battery settings
2022-02-13 arduino program script
2022-02-14 tmp water sensor delay, gsm network change temporary change
2022-02-26 no network on wake up fix + extra debug
    [sensors.ino]
2022-06-09 reset modem on error
    [network.ino, sensors.ino]
2022-07-04 UZ sleep change fix
    [network.ino, sensors.ino, vetercek_nb-iot-HW.ino]
2022-08-06 hardware serial board
2022-08-23 tmp on/off power + brownout detection
    [network.ino, sensors.ino, vetercek_nb-iot-HW.ino]
2022-11-19 uz error if doesnt respond in 1s
    [sensors.ino, vetercek_nb-iot-HW.ino]
2023-05-18 power on and gsm reset
    [BotleticsSIM7000.cpp, vetercek_SIM7070.ino, vetercek_nb-iot-HW.ino]
2023-08-22 humidity sensor
2023-09-01 change network on reset
    [network.ino, sensors.ino, vetercek_SIM7070.ino]
2023-09-16 new sensors
2024-06-30 sonic2 error count rm
    [sensors.ino, vetercek_SIM7070.ino]
2024-08-03 GSM connect bug fix
    [BotleticsSIM7000.cpp, check_network.ino, network.ino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]
2025-06-15 disable TX on ultrasonic
2025-12-23 power uz & telekom network for slo
2026-03-27 cehck ip on error
    [BotleticsSIM7000.cpp, check_network.ino, network.ino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]
